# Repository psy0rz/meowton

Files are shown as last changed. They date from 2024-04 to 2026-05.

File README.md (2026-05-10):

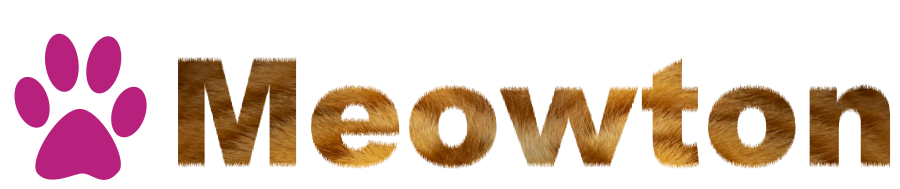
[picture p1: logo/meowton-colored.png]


# Automatic pet feeding and monitoring system 

Meowton is a system that will automaticly feed your pet and create nice graphs.

You can use it to monitor your pet or to put it on a diet.

I use it for my cats but you can also use it for dogs or perhaps other animals.

For more info look at the wiki: https://github.com/psy0rz/meowton/wiki

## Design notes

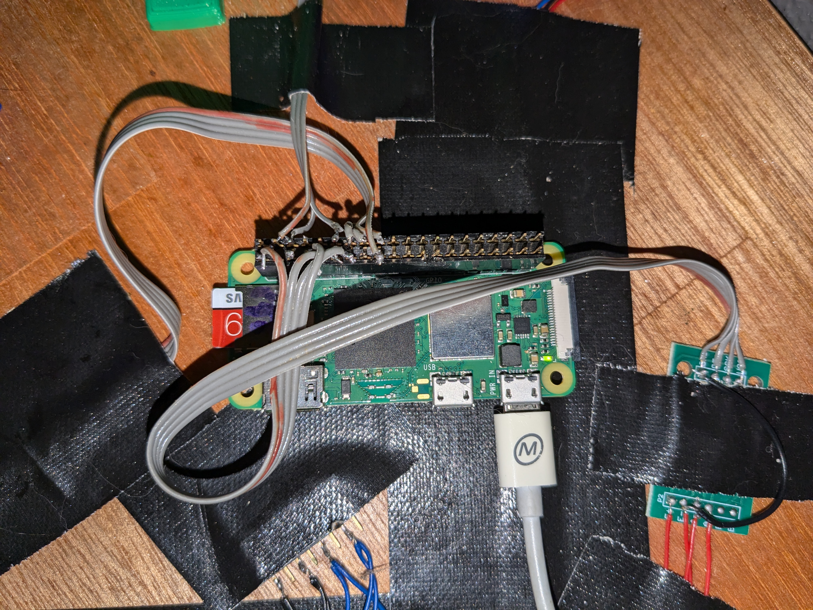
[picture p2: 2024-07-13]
3d/electronics/raspberry.jpg

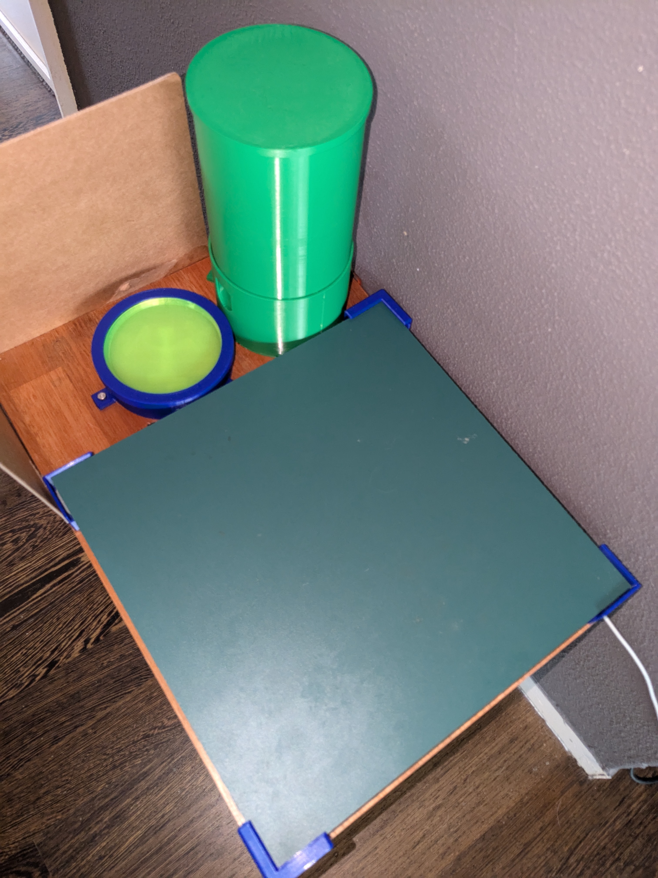
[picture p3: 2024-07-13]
3d/overview.jpg

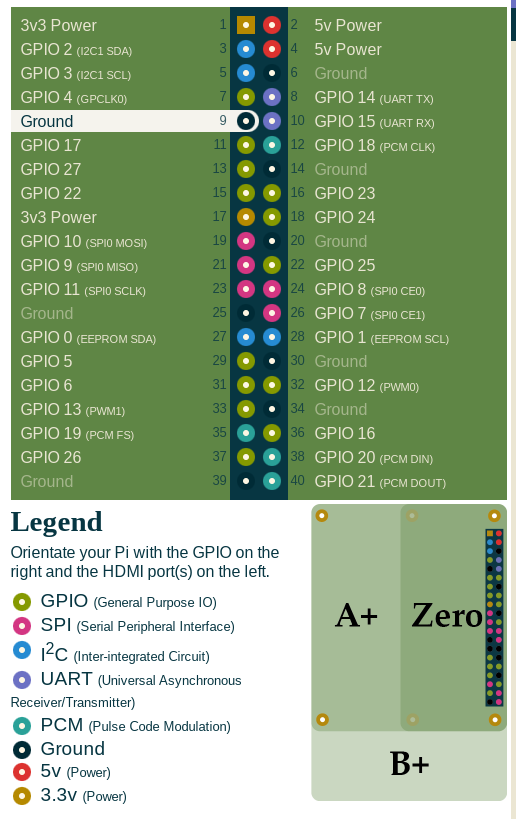
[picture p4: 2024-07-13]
3d/electronics/rpi pins.png

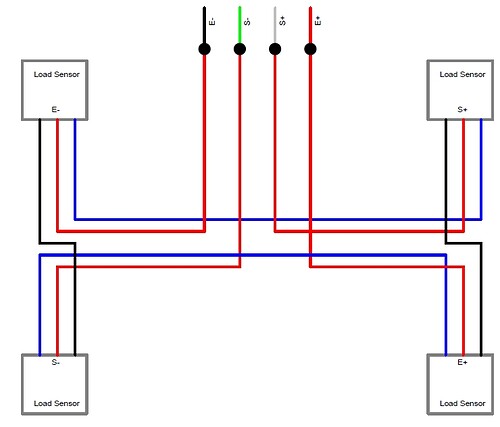
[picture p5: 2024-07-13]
3d/electronics/loadcell bridge.jpg

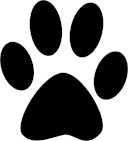
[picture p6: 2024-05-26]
src/image/pawnsmall.png

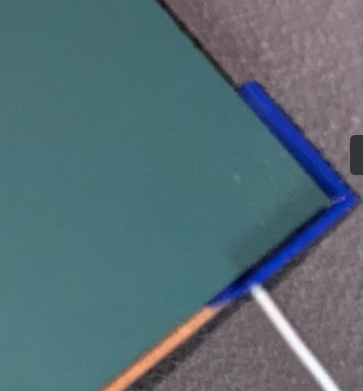
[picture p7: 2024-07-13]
3d/catscale/clearing.png

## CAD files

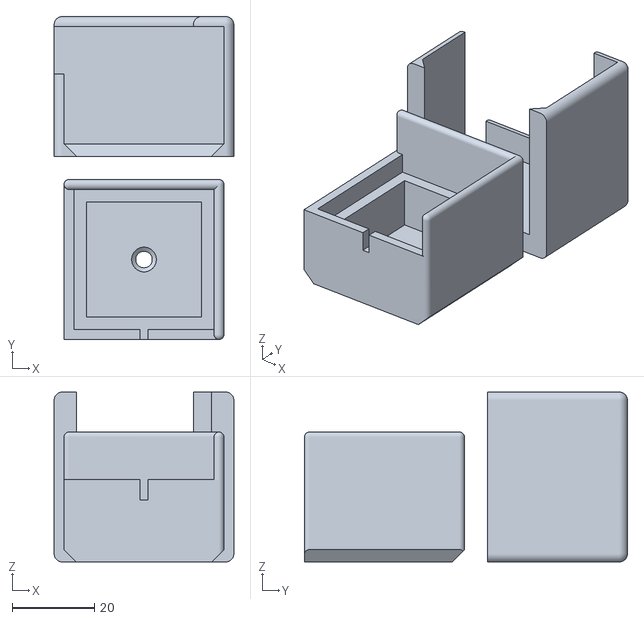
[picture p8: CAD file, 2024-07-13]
3d/catscale/cat scale v5.stl
43.6 x 78.4 x 41.2

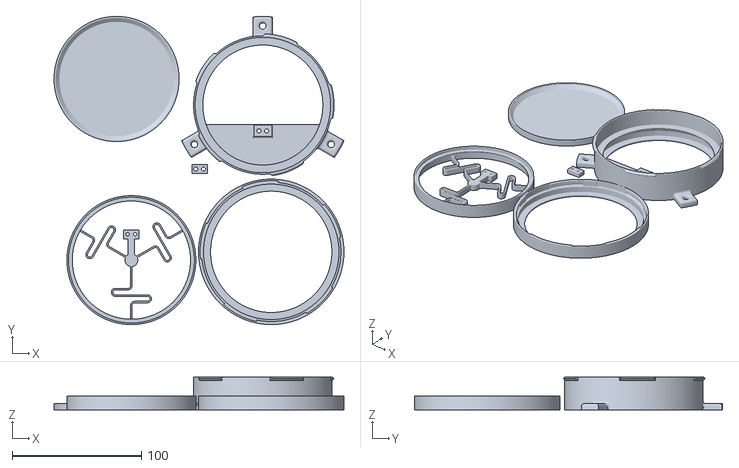
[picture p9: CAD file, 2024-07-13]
3d/foodscale/food scale v5.stl
224.8 x 238.9 x 25.5

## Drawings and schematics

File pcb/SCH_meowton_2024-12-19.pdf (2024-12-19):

### Raspberry Pi Zero Hat

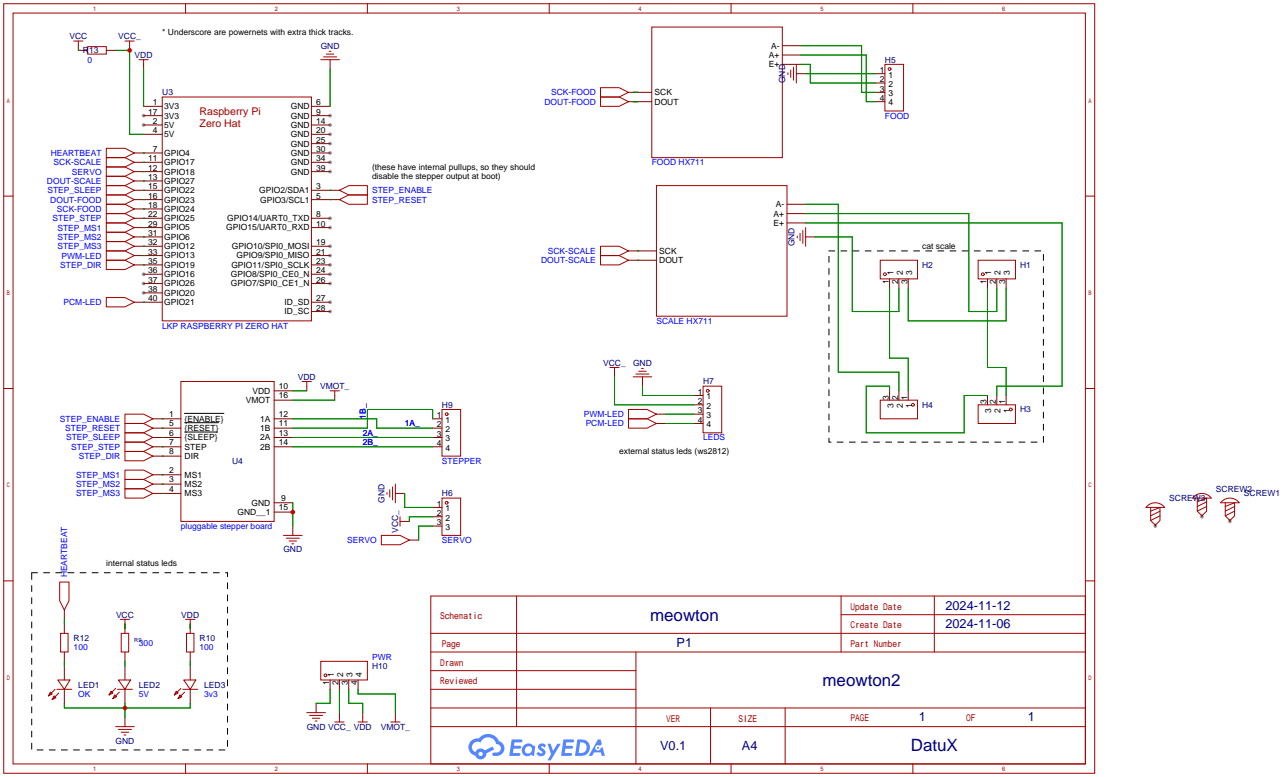
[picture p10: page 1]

* Underscore are powernets with extra thick tracks.

(these have internal pullups, so they should
disable the stepper output at boot)
STEP_ENABLE
STEP_RESET

LKP RASPBERRY PI ZERO HAT

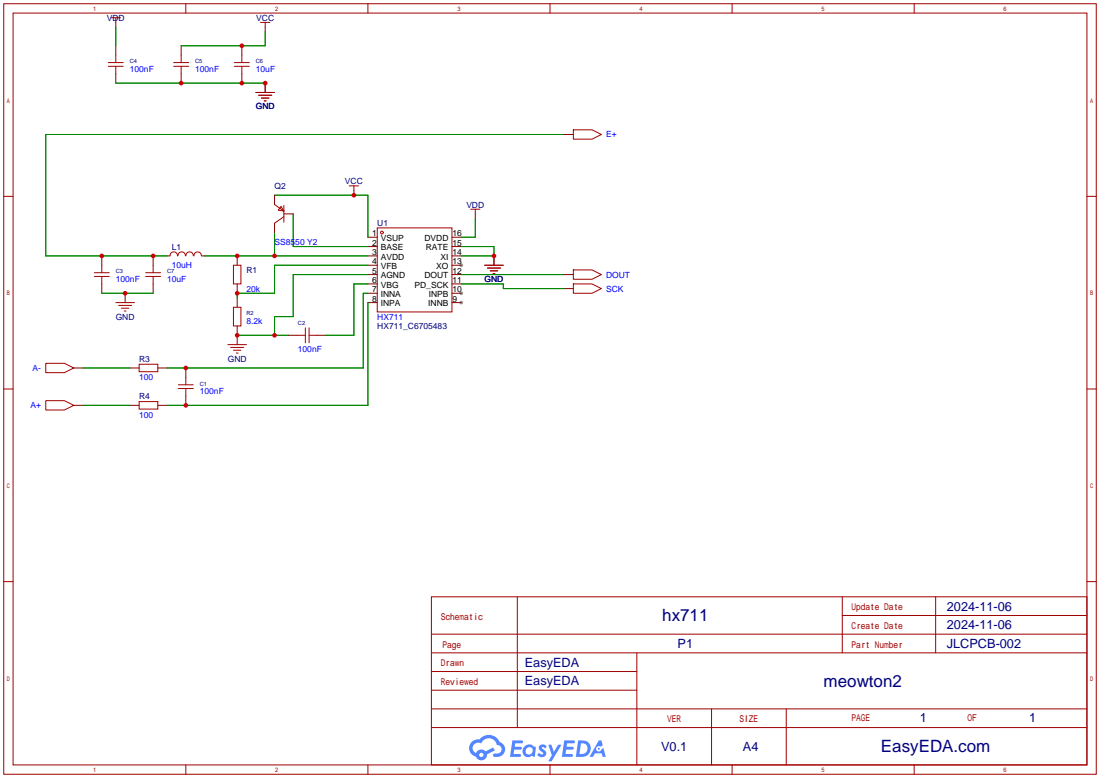
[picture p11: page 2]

INPB 10 PD_SCK 11 DOUT 12 XO 13 XI 14 RATE 15 DVDD 16

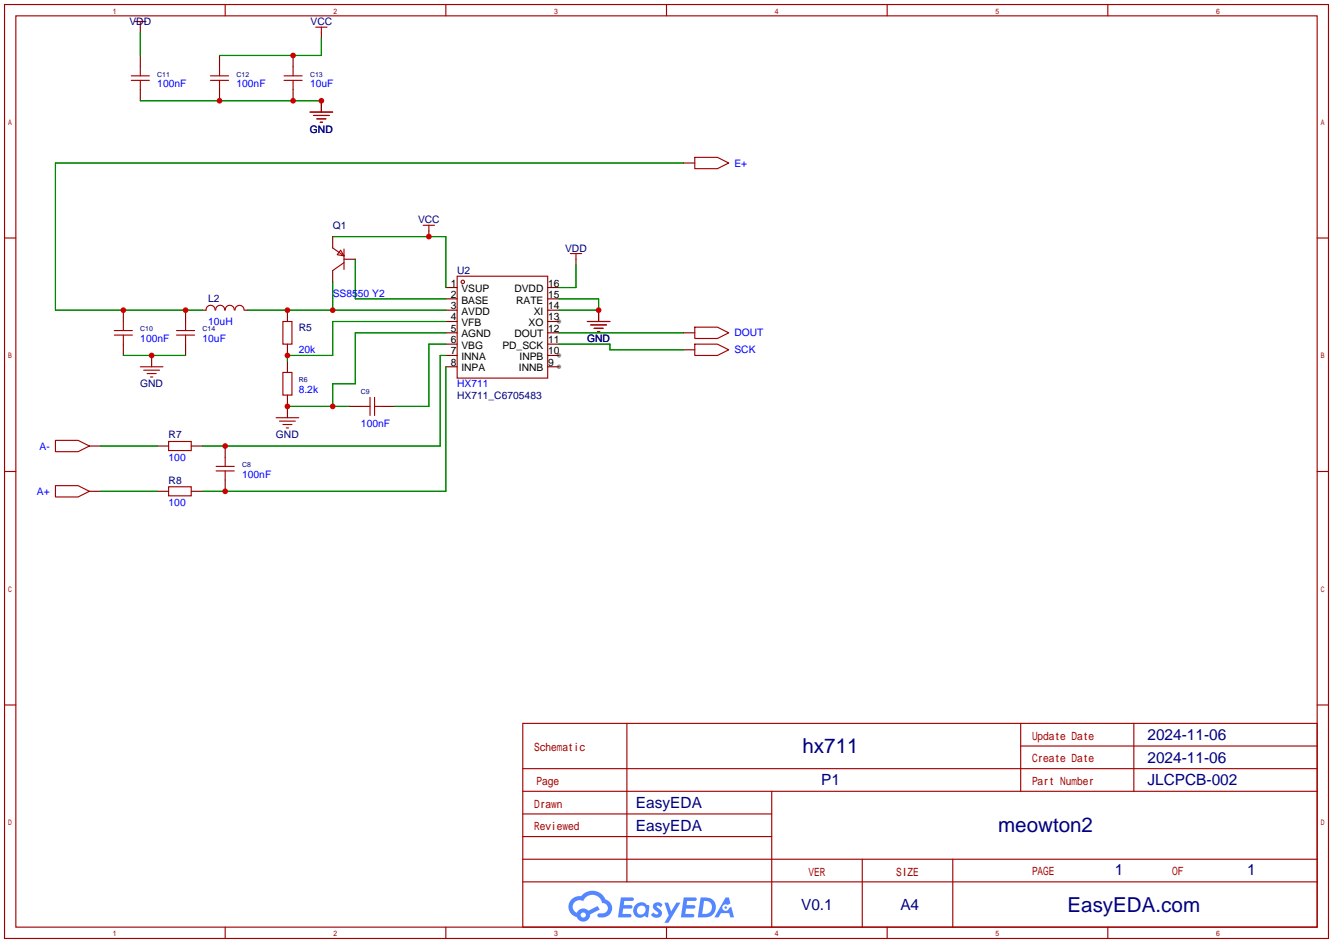
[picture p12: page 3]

INPB 10 PD_SCK 11 DOUT 12 XO 13 XI 14 RATE 15 DVDD 16

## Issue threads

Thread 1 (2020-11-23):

Bill of Materials

Rukongai, 2020-11-23:
Not really an issue, but it'd be helpful for folks looking to replicate this for a consolidated Bill of Materials!

Excellent work here. Excited to get working on it.

charlottecharles, 2021-03-16:
This is an amazing project that I would love to work on. A full bill of materials would be helpful to know how much of it I should try to tackle.

psy0rz, 2021-03-27:
Every module on the wiki starts with a Requirements section.

You're probably too lazy to open those pages and read them, but i'm much lazier that. :)

So i don't feel like creating that bill of materials and maintaining basicalaly two lists of requirements. :P

Rukongai, 2021-03-27:
I mean, I have built the feeder at this point, as well as designing a custom PCB for the project (which i'm glad to open a PR for as well)

I will gladly put together a BOM, and I appreciate the work you've done in creating this project - I was just highlighting a pain point in beginning this, which was having to move between a bunch of different pages making sure I didn't miss anything in my first order. A singular BOM would make things much easier.

psy0rz, 2021-03-27:
Oh that is great to hear! :)

I was planning to some day make a PCB for it, but its not my greatest hobby. Would love to see  a PR for it indeed.

Will it be a single pc with all the electronics on it? Or will it have mounts for the pre-fab modules i'm using?

Edwin

Rukongai, 2021-03-29:
I refactored the design a little bit, and have a new shipment of boards coming on Thursday

I will test out the new design and then if it works i'll do a PR.

This is the first time i've designed a pcb, so it's not the prettiest. I'm working on a 3rd version that's a little more complicated, that removes the need for buying a dev board or separate hx711 modules, integrating the core circuits onto a single board (and removing things like the usb ttyl circuit from the dev board) for a smaller footprint.

though that'll require a separate device for flashing the esp32.

The board itself is just a pcb that connects the dev board to the 5 hx711s with solder smd pads for all the load sensors and servo. It mounts to any flat surface with 3 m3 screws. I'd like to get it to where it can mount inside the dispenser base. I'm getting comfortable enough with fusion to try and remixing the base to that end.

It's all in all been a fun project and i've learned a ton. Thanks for putting it together.

Closed 2021-03-27.

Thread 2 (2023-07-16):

RFID reading while eating

soostdijck, 2023-07-16:
I saw your note about reading the RFID while eating. I have a couple "SureFeed Microchip Pet Feeder - MPF001". One of them broke a while ago and I took it apart. Indeed the method that they use is a giant wound coil inside the brace that the cat enters through.

I works quite well, and should do the trick for your RFID needs as well.

I can take some pics of the insides if you like.

psy0rz, 2023-07-18:
Yeah, i have one petsafe catflap thats broken, that i can use to figure out how it works. But i have no time for extra projects currently :)

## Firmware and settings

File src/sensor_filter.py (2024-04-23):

from peewee import Model, CharField, FloatField, IntegerField
from db import db


class SensorFilter(Model):
    """input filter that filters sudden spikes in the input data due to measurement errors"""
    name = CharField(primary_key=True)
    filter_diff = IntegerField(default=1000)

    class Meta:
        database = db

    def __init__(self, *args, **kwargs):
        super().__init__(*args, **kwargs)
        self.__last_value = 0
        self.__prev_value = 0
        self.last_difference = 0

    def valid(self, value:int):
        ok = False
        diff = abs(value - self.__last_value)
        self.last_difference = diff
        if diff <= self.filter_diff:
            ok = True
        else:
            diff = abs(value - self.__prev_value)
            if diff <= self.filter_diff:
                ok = True

        self.__prev_value = self.__last_value
        self.__last_value = value

        return ok


db.create_tables([SensorFilter])

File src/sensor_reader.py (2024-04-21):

import asyncio
import random
import threading
import time
from typing import TypeAlias, Callable

MeasurementCallback: TypeAlias = Callable[[int], None]


class SensorReader:
    """read data from hardware via a thread, and calls measurement_callback. (in a threadsafe way)"""

    __loop: asyncio.AbstractEventLoop

    def __init__(self, name: str, data_pin: int, clk_pin: int, sim: bool,
                 measurement_callback: MeasurementCallback):

        self.sim_value = 0
        self.sim_noise = 20

        self.__data_pin = data_pin
        self.__clk_pin = clk_pin
        self.__sim = sim

        self.__thread: threading.Thread | None = None
        self.__stop_event = threading.Event()

        # self.__loop = asyncio.get_event_loop()
        self.__measurement_callback = measurement_callback

    def simulator_thread(self):

        while not self.__stop_event.is_set():
            raw_value = self.sim_value + int(random.normalvariate(0, self.sim_noise))
            # print(f"jan {raw_value}")
            self.__loop.call_soon_threadsafe(self.__measurement_callback, raw_value)

            time.sleep(0.1)

    def reader_thread(self):
        from RPi import GPIO
        from hx711 import HX711

        GPIO.setwarnings(False)

        hx711 = HX711(
            dout_pin=self.__data_pin,
            pd_sck_pin=self.__clk_pin,
            channel='A',
            gain=128
        )

        hx711.reset()  # Before we start, reset the HX711 (not obligate)

        while not self.__stop_event.is_set():
            raw_value = hx711._read()
            if raw_value is not False:
                self.__loop.call_soon_threadsafe(self.__measurement_callback, raw_value)

    def start(self):
        """start reader thread, or simtrhead if data/clk are not specified"""

        if self.__thread is not None:
            raise Exception("Thread already started")

        self.__loop = asyncio.get_running_loop()

        self.__stop_event.clear()

        #NOTE: via seperate async run_in_executor will be slower/more overhead
        if self.__sim:
            self.__thread = threading.Thread(target=self.simulator_thread)
        else:
            self.__thread = threading.Thread(target=self.reader_thread)

        self.__thread.start()

    def stop(self):
        self.__stop_event.set()
        self.__thread.join()
        self.__thread = None

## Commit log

2016-12-03 initial commit. working prototype
2018-04-02 better led feedback
2018-09-04 also feed automaticly when all cats may have food. (prevents cat camping on the scale)
    [meowton.py]
2018-09-30 added calibration algorithms for whole scale, instead of per loadcell. thanks to zmatt.
2018-12-01 save calibration in state
2018-12-19 generalized calibrating. calibrating/saving/loading works
2018-12-20 fixed feeding and realtime quotas
    [cat.py, displayio.py]
2018-12-20 fixes. show food quota in minutes
    [cat.py, displayio.py, scale.py]
2018-12-26 small refactor. added cam hack and temporary foodscale error work around
    [meowton.py]
2018-12-27 temoprary use 5kg loadcell for food
2019-01-09 refactoring. test for loadcell errors
    [main.kicad_pcb, main.sch]
2019-01-10 made calibrating routine much more flexible
2019-01-13 fixes. slower servo settings to prevent jams
    [display.py, meowton.py, scale.py]
2019-01-13 fixed my foodscale sensor, so its a 100g loadcell again instead of the 5kg temporary hack
    [meowton.py, scale.py]
2019-01-20 nicer default pinout. automaticly swap clock/data. fixes
    [display.py, meowton.py]
2019-01-21 tuned calibration. using timer instead of sched.
2019-07-22 added stuff to prusaprinters.org as well as here
    [catscale_2.66.stl, dispense_4_v101_common_parts.stl, dispense_4_v101_silo.stl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]
2019-12-23 disabling irqs not needed anymore? fixes
    [meowton.py]
2020-02-03 filter noise
2020-02-04 changed hx711 to spi mode. working on timing issues
    [meowton.py, scale.py]
2020-02-05 made calibration very nice
2020-04-19 start with calibrating false
2020-06-28 servo stored in state, will be configurable. nicer repl output for states
2020-06-30 working on servo settings
2020-06-30 servo testing
2020-06-30 finished servo config and testing
2020-07-28 print usefull realtime info via serial
2020-08-08 fix some quota update bugs for new cats. quota on status page is now updated in realtime.
    [cat.py, meowton.py]
2020-08-08 latest stl files are on thingiverse
    [catscale_2.66.stl, dispense_4_v101_common_parts.stl, dispense_4_v101_silo.stl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]
2022-04-24 now increase quota and always feed at fixed times to give the cat a schedule and prevent endless waiting
    [cat.py, meowton.py]
2024-02-06 seems to work well enough with regular 50kg sensors in bridge mode (about 10g precion )
2024-07-13 models and images
    [food scale v3.stl]
2024-07-13 wrong version
    [food scale v5.stl]
2024-10-29 pcb work in progress
    [meowton.kicad_pcb, meowton.kicad_sch]
2024-12-19 new pcb
    [meowton.kicad_pcb, meowton.kicad_sch]
2024-12-19 status led
2025-05-26 group per 2 days to reduce noise
    [ui_page_stats.py]
2026-01-08 pcb for easyeda pro/jlc pcb
